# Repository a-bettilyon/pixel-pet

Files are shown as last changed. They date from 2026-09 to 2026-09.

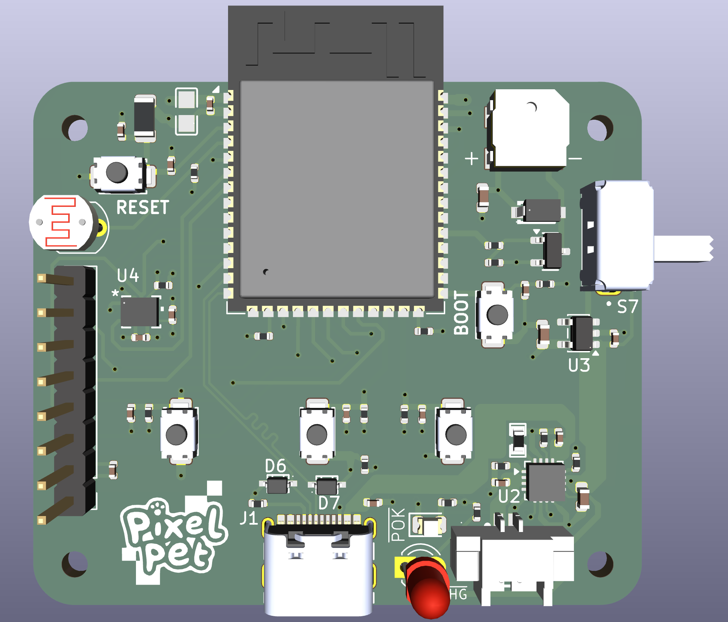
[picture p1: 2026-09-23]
hardware/images/VirtualPetBoardRenderV1.png

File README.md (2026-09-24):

PixelPetLogoFullColor

<br>

⚠️ **Project Status:** Active Development / Work in Progress

<br clear="left">
<br>

PixelPetV3Disassembled4

<br>

Pixel Pet is a handheld ESP32-S3-based device that brings back the virtual pet experience, built entirely from scratch, including custom PCB, 3D printed enclosure, and original C++ firmware.

The board features a 4-layer custom PCB design (ESP32-S3-WROOM-1, ST7789 TFT display, BMI323 IMU, LiPo charging with power path management, and tactile button input), fabricated and assembled through JLCPCB. The enclosure is designed in Fusion 360 and 3D printed to house the board, display, and battery in a compact handheld form factor.

This project was built as a hands-on portfolio piece to demonstrate end-to-end embedded systems and PCB design skills across schematic capture, layout, firmware development, and mechanical design.

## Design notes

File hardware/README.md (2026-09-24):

# Hardware

⚠️ **Status:** Active development. PCB currently in bring-up and testing.

KiCad project for the Pixel Pet custom PCB, an ESP32-S3-based board with display, IMU, charging circuit, and user I/O.

## Opening the project

Requires [KiCad](https://www.kicad.org/) (developed in v8). Multiple custom part libraries are used, see  `/libraries`.
## Key design notes

- ESP32-S3-WROOM-1 module, 4-layer board
- BQ24079 LiPo charger with power path management
- BMI323 IMU (SPI), ST7789 TFT display
- Targeting JLCPCB fabrication + SMT assembly, with select hand-soldered THT parts

## Gerbers / BOM freshness

Files in `/gerbers` and `bom.csv` are exported directly from the current `.kicad_pcb`/`.kicad_sch`. If you're building from this repo, pull these rather than any older exports that may exist elsewhere in project history.

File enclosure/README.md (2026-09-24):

# Enclosure

⚠️ **Status:** Active development.

<br>

PixelPetAssembledView3

<br>

3D-printable enclosure for the Pixel Pet handheld, designed around the PCB from `/hardware`.

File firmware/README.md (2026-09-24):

# Firmware

⚠️ **Status:** Active development.

## Building

_(Add your toolchain details here, e.g.)_
- Built with the Arduino IDE / PlatformIO targeting ESP32-S3
- Required libraries: _7Semi BMI323, Adafruit GFX Library, Adafruit ST7735 and ST7789 Library_

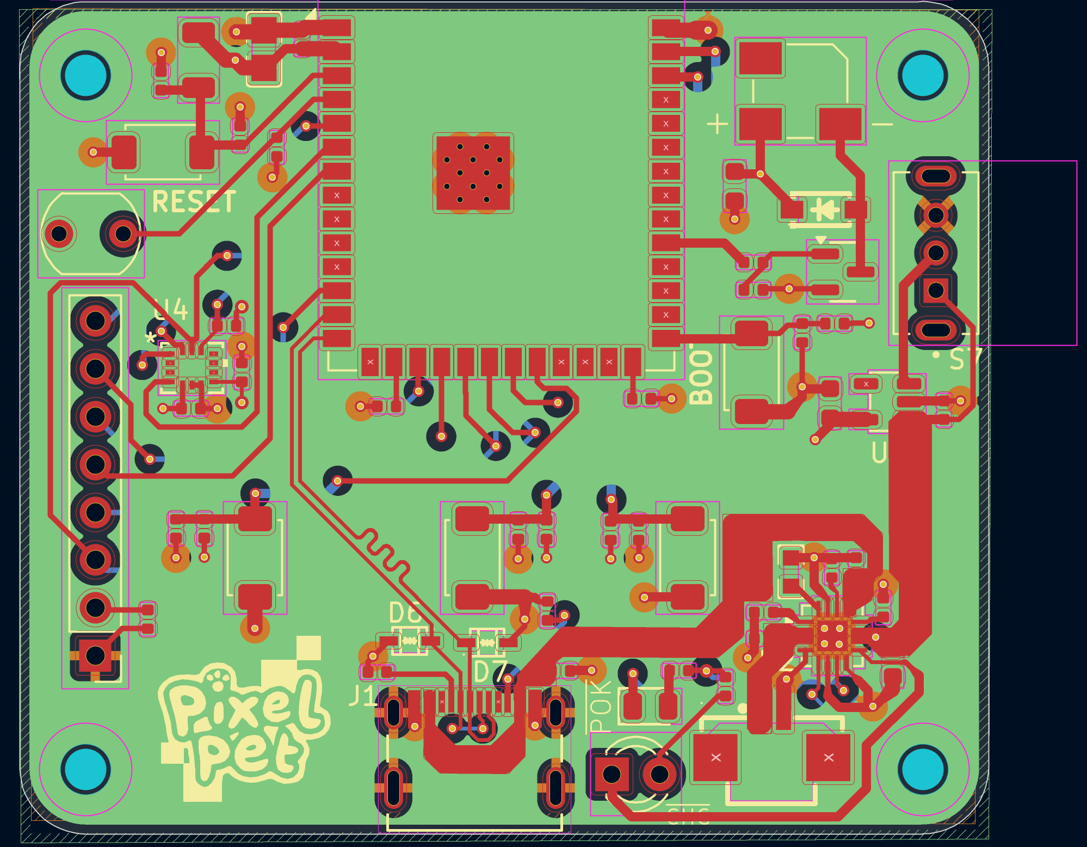
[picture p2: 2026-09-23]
hardware/images/VirtualPetBoardPCBAll.png

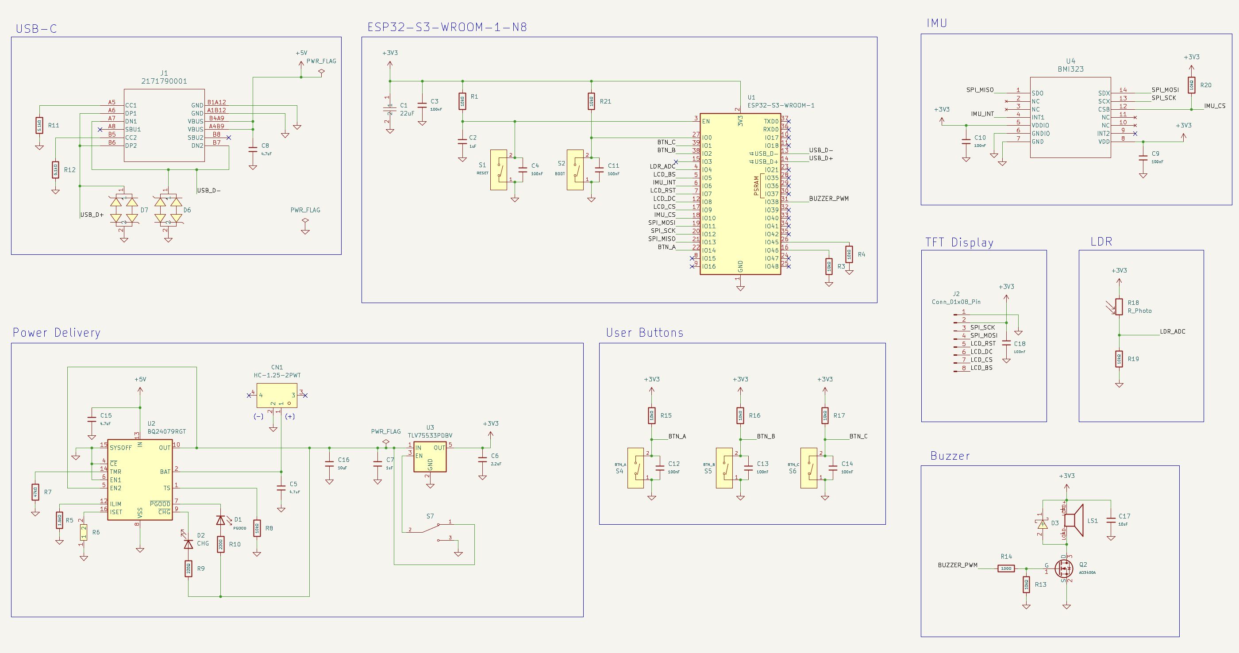
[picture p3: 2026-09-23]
hardware/images/VirtualPetBoardSchematicV1.png

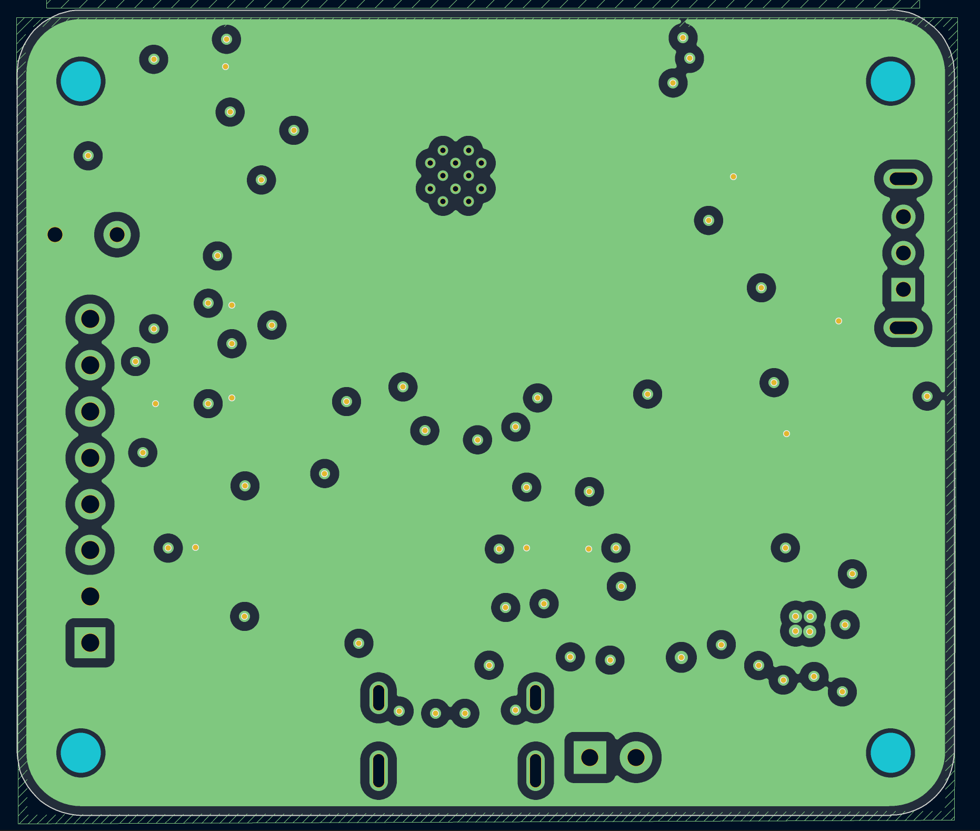
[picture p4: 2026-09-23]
hardware/images/VirtualPetBoardPCBLn1Cu.png

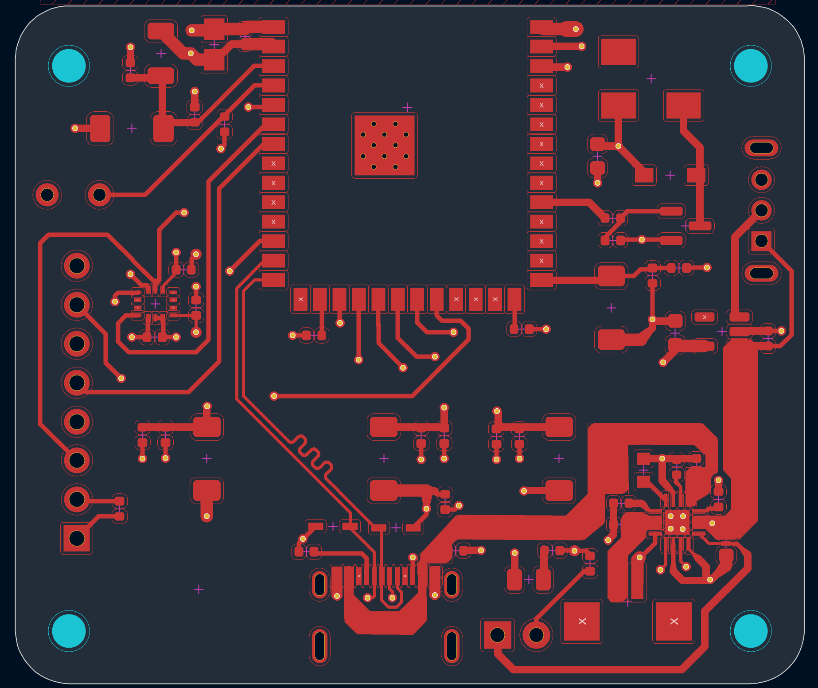
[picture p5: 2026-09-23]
hardware/images/VirtualPetBoardPCBFCu.png

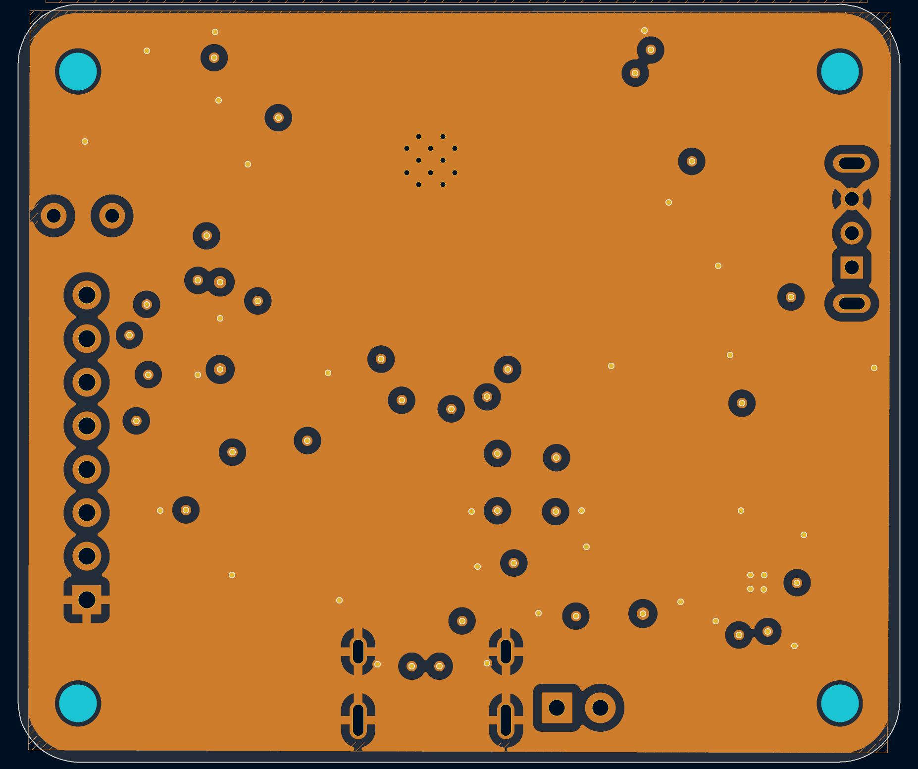
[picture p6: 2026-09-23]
hardware/images/VirtualPetBoardPCBLn2Cu.png

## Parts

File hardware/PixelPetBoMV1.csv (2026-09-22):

 | Status | Reference | Value | Footprint | LCSC | Part | Manufacturer | Description | Datasheet/Listing
1 | Basic | C1 | 22uF | C0805 | C45783 | CL21A226MAQNNNE | SAMSUNG(三星) |  | https://lcsc.com/product-detail/Multilayer-Ceramic-Capacitors-MLCC-SMD-SMT_SAMSUNG_CL21A226MAQNNNE_22uF-226-20-25V_C45783.html
2 | Basic | C2 | 1uF | C_0402 | C52923 | CL05A105KA5NQNC | Samsung Electro-Mechanics | 25V 1uF X5R ±10% 0402 Multilayer Ceramic Capacitors MLCC - SMD/SMT ROHS | https://www.lcsc.com/datasheet/lcsc_datasheet_2304140030_Samsung-Electro-Mechanics-CL05A105KA5NQNC_C52923.pdf
3 | Basic | C3 | 100nF | C_0402 | C1525 | CL05B104KO5NNNC | Samsung Electro-Mechanics | 16V 100nF X7R ±10% 0402 Multilayer Ceramic Capacitors MLCC - SMD/SMT ROHS | https://www.lcsc.com/datasheet/lcsc_datasheet_2304140030_Samsung-Electro-Mechanics-CL05B104KO5NNNC_C1525.pdf
4 | Basic | C4 | 100nF | C_0402 | C1525 | CL05B104KO5NNNC | Samsung Electro-Mechanics | 16V 100nF X7R ±10% 0402 Multilayer Ceramic Capacitors MLCC - SMD/SMT ROHS | https://www.lcsc.com/datasheet/lcsc_datasheet_2304140030_Samsung-Electro-Mechanics-CL05B104KO5NNNC_C1525.pdf
5 | Basic | C5 | 4.7uF | C_0402 | C23733 | CL05A475MP5NRNC | Samsung Electro-Mechanics | 10V 4.7uF X5R ±20% 0402 Multilayer Ceramic Capacitors MLCC - SMD/SMT ROHS | https://www.lcsc.com/datasheet/lcsc_datasheet_2304140030_Samsung-Electro-Mechanics-CL05A475MP5NRNC_C23733.pdf
6 | Basic | C6 | 2.2uF | C_0603 | C23630 | CL10A225KO8NNNC | Samsung Electro-Mechanics | 16V 2.2uF X5R ±10% 0603 Multilayer Ceramic Capacitors MLCC - SMD/SMT ROHS | https://www.lcsc.com/datasheet/lcsc_datasheet_2304140030_Samsung-Electro-Mechanics-CL10A225KO8NNNC_C23630.pdf
7 | Basic | C7 | 1uF | C_0402 | C52923 | CL05A105KA5NQNC | Samsung Electro-Mechanics | 25V 1uF X5R ±10% 0402 Multilayer Ceramic Capacitors MLCC - SMD/SMT ROHS | https://www.lcsc.com/datasheet/lcsc_datasheet_2304140030_Samsung-Electro-Mechanics-CL05A105KA5NQNC_C52923.pdf
8 | Basic | C8 | 4.7uF | C_0402 | C23733 | CL05A475MP5NRNC | Samsung Electro-Mechanics | 10V 4.7uF X5R ±20% 0402 Multilayer Ceramic Capacitors MLCC - SMD/SMT ROHS | https://www.lcsc.com/datasheet/lcsc_datasheet_2304140030_Samsung-Electro-Mechanics-CL05A475MP5NRNC_C23733.pdf
9 | Basic | C9 | 100nF | C_0402 | C1525 | CL05B104KO5NNNC | Samsung Electro-Mechanics | 16V 100nF X7R ±10% 0402 Multilayer Ceramic Capacitors MLCC - SMD/SMT ROHS | https://www.lcsc.com/datasheet/lcsc_datasheet_2304140030_Samsung-Electro-Mechanics-CL05B104KO5NNNC_C1525.pdf
10 | Basic | C10 | 100nF | C_0402 | C1525 | CL05B104KO5NNNC | Samsung Electro-Mechanics | 16V 100nF X7R ±10% 0402 Multilayer Ceramic Capacitors MLCC - SMD/SMT ROHS | https://www.lcsc.com/datasheet/lcsc_datasheet_2304140030_Samsung-Electro-Mechanics-CL05B104KO5NNNC_C1525.pdf
11 | Basic | C11 | 100nF | C_0402 | C1525 | CL05B104KO5NNNC | Samsung Electro-Mechanics | 16V 100nF X7R ±10% 0402 Multilayer Ceramic Capacitors MLCC - SMD/SMT ROHS | https://www.lcsc.com/datasheet/lcsc_datasheet_2304140030_Samsung-Electro-Mechanics-CL05B104KO5NNNC_C1525.pdf
12 | Basic | C12 | 100nF | C_0402 | C1525 | CL05B104KO5NNNC | Samsung Electro-Mechanics | 16V 100nF X7R ±10% 0402 Multilayer Ceramic Capacitors MLCC - SMD/SMT ROHS | https://www.lcsc.com/datasheet/lcsc_datasheet_2304140030_Samsung-Electro-Mechanics-CL05B104KO5NNNC_C1525.pdf
13 | Basic | C13 | 100nF | C_0402 | C1525 | CL05B104KO5NNNC | Samsung Electro-Mechanics | 16V 100nF X7R ±10% 0402 Multilayer Ceramic Capacitors MLCC - SMD/SMT ROHS | https://www.lcsc.com/datasheet/lcsc_datasheet_2304140030_Samsung-Electro-Mechanics-CL05B104KO5NNNC_C1525.pdf
14 | Basic | C14 | 100nF | C_0402 | C1525 | CL05B104KO5NNNC | Samsung Electro-Mechanics | 16V 100nF X7R ±10% 0402 Multilayer Ceramic Capacitors MLCC - SMD/SMT ROHS | https://www.lcsc.com/datasheet/lcsc_datasheet_2304140030_Samsung-Electro-Mechanics-CL05B104KO5NNNC_C1525.pdf
15 | Basic | C15 | 4.7uF | C_0402 | C23733 | CL05A475MP5NRNC | Samsung Electro-Mechanics | 10V 4.7uF X5R ±20% 0402 Multilayer Ceramic Capacitors MLCC - SMD/SMT ROHS | https://www.lcsc.com/datasheet/lcsc_datasheet_2304140030_Samsung-Electro-Mechanics-CL05A475MP5NRNC_C23733.pdf
16 | Basic | C16 | 10uF | C_0603 | C19702 | CL10A106KP8NNNC | Samsung Electro-Mechanics | 10V 10uF X5R ±10% 0603 Multilayer Ceramic Capacitors MLCC - SMD/SMT ROHS | https://www.lcsc.com/datasheet/lcsc_datasheet_2304140030_Samsung-Electro-Mechanics-CL10A106KP8NNNC_C19702.pdf
17 | Basic | C17 | 10uF | C_0603 | C19702 | CL10A106KP8NNNC | Samsung Electro-Mechanics | 10V 10uF X5R ±10% 0603 Multilayer Ceramic Capacitors MLCC - SMD/SMT ROHS | https://www.lcsc.com/datasheet/lcsc_datasheet_2304140030_Samsung-Electro-Mechanics-CL10A106KP8NNNC_C19702.pdf
18 | Basic | C18 | 100nF | C_0402 | C1525 | CL05B104KO5NNNC | Samsung Electro-Mechanics | 16V 100nF X7R ±10% 0402 Multilayer Ceramic Capacitors MLCC - SMD/SMT ROHS | https://www.lcsc.com/datasheet/lcsc_datasheet_2304140030_Samsung-Electro-Mechanics-CL05B104KO5NNNC_C1525.pdf
19 | Basic | R1 | 10kΩ | R_1206 | C17902 | 1206W4F1002T5E | UNI-ROYAL(Uniroyal Elec) | 250mW Thick Film Resistors 200V ±100ppm/°C ±1% 10kΩ 1206 Chip Resistor - Surface Mount ROHS | https://www.lcsc.com/datasheet/lcsc_datasheet_2206010145_UNI-ROYAL-Uniroyal-Elec-1206W4F1002T5E_C17902.pdf
20 | Basic | R3 | 10kΩ | R_0402 | C25744 | 0402WGF1002TCE | UNI-ROYAL(Uniroyal Elec) | 62.5mW Thick Film Resistors 50V ±100ppm/°C ±1% 10kΩ 0402 Chip Resistor - Surface Mount ROHS | https://www.lcsc.com/datasheet/lcsc_datasheet_2411221126_UNI-ROYAL-Uniroyal-Elec-0402WGF1002TCE_C25744.pdf
21 | Basic | R4 | 10kΩ | R_0402 | C25744 | 0402WGF1002TCE | UNI-ROYAL(Uniroyal Elec) | 62.5mW Thick Film Resistors 50V ±100ppm/°C ±1% 10kΩ 0402 Chip Resistor - Surface Mount ROHS | https://www.lcsc.com/datasheet/lcsc_datasheet_2411221126_UNI-ROYAL-Uniroyal-Elec-0402WGF1002TCE_C25744.pdf
22 | Basic | R5 | 1.5kΩ | R_0402 | C25867 | 0402WGF1501TCE | UNI-ROYAL(Uniroyal Elec) | 62.5mW Thick Film Resistors 50V ±100ppm/°C ±1% 1.5kΩ 0402 Chip Resistor - Surface Mount ROHS | https://www.lcsc.com/datasheet/lcsc_datasheet_2206010045_UNI-ROYAL-Uniroyal-Elec-0402WGF1501TCE_C25867.pdf
23 | Basic | R6 | 3.9k | R0603 | C23018 | 0603WAF3901T5E | UNI-ROYAL(厚声) | 3.9KΩ (3901) ±1% | https://lcsc.com/product-detail/Chip-Resistor-Surface-Mount-UniOhm_3-9KR-3901-1_C23018.html
24 | Basic | R7 | 47kΩ | R_0402 | C25792 | 0402WGF4702TCE | UNI-ROYAL(Uniroyal Elec) | 62.5mW Thick Film Resistors 50V ±100ppm/°C ±1% 47kΩ 0402 Chip Resistor - Surface Mount ROHS | https://www.lcsc.com/datasheet/lcsc_datasheet_2206010100_UNI-ROYAL-Uniroyal-Elec-0402WGF4702TCE_C25792.pdf
25 | Basic | R8 | 10kΩ | R_0402 | C25744 | 0402WGF1002TCE | UNI-ROYAL(Uniroyal Elec) | 62.5mW Thick Film Resistors 50V ±100ppm/°C ±1% 10kΩ 0402 Chip Resistor - Surface Mount ROHS | https://www.lcsc.com/datasheet/lcsc_datasheet_2411221126_UNI-ROYAL-Uniroyal-Elec-0402WGF1002TCE_C25744.pdf
26 | Basic | R9 | 220Ω | R_0402 | C25091 | 0402WGF2200TCE | UNI-ROYAL(Uniroyal Elec) | 62.5mW Thick Film Resistors 50V ±100ppm/°C ±1% 220Ω 0402 Chip Resistor - Surface Mount ROHS | https://www.lcsc.com/datasheet/lcsc_datasheet_2205311900_UNI-ROYAL-Uniroyal-Elec-0402WGF2200TCE_C25091.pdf
27 | Basic | R10 | 220Ω | R_0402 | C25091 | 0402WGF2200TCE | UNI-ROYAL(Uniroyal Elec) | 62.5mW Thick Film Resistors 50V ±100ppm/°C ±1% 220Ω 0402 Chip Resistor - Surface Mount ROHS | https://www.lcsc.com/datasheet/lcsc_datasheet_2205311900_UNI-ROYAL-Uniroyal-Elec-0402WGF2200TCE_C25091.pdf
28 | Basic | R11 | 5.1kΩ | R_0402 | C25905 | 0402WGF5101TCE | UNI-ROYAL(Uniroyal Elec) | 62.5mW Thick Film Resistors 50V ±100ppm/°C ±1% 5.1kΩ 0402 Chip Resistor - Surface Mount ROHS | https://www.lcsc.com/datasheet/lcsc_datasheet_2206010045_UNI-ROYAL-Uniroyal-Elec-0402WGF5101TCE_C25905.pdf
29 | Basic | R12 | 5.1kΩ | R_0402 | C25905 | 0402WGF5101TCE | UNI-ROYAL(Uniroyal Elec) | 62.5mW Thick Film Resistors 50V ±100ppm/°C ±1% 5.1kΩ 0402 Chip Resistor - Surface Mount ROHS | https://www.lcsc.com/datasheet/lcsc_datasheet_2206010045_UNI-ROYAL-Uniroyal-Elec-0402WGF5101TCE_C25905.pdf
30 | Basic | R13 | 10kΩ | R_0402 | C25744 | 0402WGF1002TCE | UNI-ROYAL(Uniroyal Elec) | 62.5mW Thick Film Resistors 50V ±100ppm/°C ±1% 10kΩ 0402 Chip Resistor - Surface Mount ROHS | https://www.lcsc.com/datasheet/lcsc_datasheet_2411221126_UNI-ROYAL-Uniroyal-Elec-0402WGF1002TCE_C25744.pdf
31 | Basic | R14 | 100Ω | R_0402 | C25076 | 0402WGF1000TCE | UNI-ROYAL(Uniroyal Elec) | 62.5mW Thick Film Resistors 50V ±1% ±200ppm/°C 100Ω 0402 Chip Resistor - Surface Mount ROHS | https://www.lcsc.com/datasheet/lcsc_datasheet_2205311900_UNI-ROYAL-Uniroyal-Elec-0402WGF1000TCE_C25076.pdf
32 | Basic | R15 | 10kΩ | R_0402 | C25744 | 0402WGF1002TCE | UNI-ROYAL(Uniroyal Elec) | 62.5mW Thick Film Resistors 50V ±100ppm/°C ±1% 10kΩ 0402 Chip Resistor - Surface Mount ROHS | https://www.lcsc.com/datasheet/lcsc_datasheet_2411221126_UNI-ROYAL-Uniroyal-Elec-0402WGF1002TCE_C25744.pdf
33 | Basic | R16 | 10kΩ | R_0402 | C25744 | 0402WGF1002TCE | UNI-ROYAL(Uniroyal Elec) | 62.5mW Thick Film Resistors 50V ±100ppm/°C ±1% 10kΩ 0402 Chip Resistor - Surface Mount ROHS | https://www.lcsc.com/datasheet/lcsc_datasheet_2411221126_UNI-ROYAL-Uniroyal-Elec-0402WGF1002TCE_C25744.pdf
34 | Basic | R17 | 10kΩ | R_0402 | C25744 | 0402WGF1002TCE | UNI-ROYAL(Uniroyal Elec) | 62.5mW Thick Film Resistors 50V ±100ppm/°C ±1% 10kΩ 0402 Chip Resistor - Surface Mount ROHS | https://www.lcsc.com/datasheet/lcsc_datasheet_2411221126_UNI-ROYAL-Uniroyal-Elec-0402WGF1002TCE_C25744.pdf
35 | Basic | R18 | R_Photo | R_LDR_5.1x4.3mm_P3.4mm_Vertical |  |  |  | Photoresistor
36 | Basic | R19 | 10kΩ | R_0402 | C25744 | 0402WGF1002TCE | UNI-ROYAL(Uniroyal Elec) | 62.5mW Thick Film Resistors 50V ±100ppm/°C ±1% 10kΩ 0402 Chip Resistor - Surface Mount ROHS | https://www.lcsc.com/datasheet/lcsc_datasheet_2411221126_UNI-ROYAL-Uniroyal-Elec-0402WGF1002TCE_C25744.pdf
37 | Basic | R20 | 10kΩ | R_0402 | C25744 | 0402WGF1002TCE | UNI-ROYAL(Uniroyal Elec) | 62.5mW Thick Film Resistors 50V ±100ppm/°C ±1% 10kΩ 0402 Chip Resistor - Surface Mount ROHS | https://www.lcsc.com/datasheet/lcsc_datasheet_2411221126_UNI-ROYAL-Uniroyal-Elec-0402WGF1002TCE_C25744.pdf
38 | Basic | R21 | 10kΩ | R_0402 | C25744 | 0402WGF1002TCE | UNI-ROYAL(Uniroyal Elec) | 62.5mW Thick Film Resistors 50V ±100ppm/°C ±1% 10kΩ 0402 Chip Resistor - Surface Mount ROHS | https://www.lcsc.com/datasheet/lcsc_datasheet_2411221126_UNI-ROYAL-Uniroyal-Elec-0402WGF1002TCE_C25744.pdf
39 |  | D1 | PGOOD | D_0805 | C2297 | KT-0805G | Hubei KENTO Elec | Emerald 0805 LED Indication - Discrete ROHS | https://www.lcsc.com/datasheet/lcsc_datasheet_1806151820_Hubei-KENTO-Elec-KT-0805G_C2297.pdf
40 |  | D2 | CHG | LED_D3.0mm |  |  |  | Light emitting diode
41 |  | D3 | B5819W_C8598 | SOD-123_L2.7-W1.6-LS3.7-RD-1 | C8598 | B5819W SL | CJ(江苏长电/长晶) | B5819W SL | https://lcsc.com/product-detail/Schottky-Barrier-Diodes-SBD_B5819W-SL_C8598.html
42 |  | D6 | PTVSUC3D5VB | SOD-323_L1.8-W1.3-LS2.5-BI | C918847 | PTVSUC3D5VB | Prisemi(芯导) |  | https://lcsc.com/product-detail/TVS_Shanghai-Prisemi-Elec-PTVSUC3D5VB_C918847.html
43 |  | D7 | PTVSUC3D5VB | SOD-323_L1.8-W1.3-LS2.5-BI | C918847 | PTVSUC3D5VB | Prisemi(芯导) |  | https://lcsc.com/product-detail/TVS_Shanghai-Prisemi-Elec-PTVSUC3D5VB_C918847.html
44 |  | U1 | ESP32-S3-WROOM-1 | ESP32-S3-WROOM-1-Custom |  |  |  | RF Module, ESP32-S3 SoC, Wi-Fi 802.11b/g/n, Bluetooth, BLE, 32-bit, 3.3V, onboard antenna, SMD | https://www.espressif.com/sites/default/files/documentation/esp32-s3-wroom-1_wroom-1u_datasheet_en.pdf
45 |  | U2 | BQ24079RGT | VQFN-16-1EP_3x3mm_P0.5mm_EP1.6x1.6mm |  |  |  | USB-Friendly Li-Ion Battery Charger and Power-Path Management, VQFN-16 | http://www.ti.com/lit/ds/symlink/bq24079.pdf
46 |  | U3 | TLV75533PDBV | SOT-23-5 |  |  |  | 500mA Low Dropout Voltage Regulator, Fixed Output 3.3V, SOT-23-5 | http://www.ti.com/lit/ds/symlink/tlv755p.pdf
47 | Extended - JLC Assembly | U4 | BMI323 | BMI323_BOS
48 | Extended - JLC Assembly | CN1 | HC-1.25-2PWT | CONN-SMD_2P-P1.25-HC-1.25-2PWT | C2845379 | HC-1.25-2PWT | HCTL(华灿天禄) |  | https://www.lcsc.com/datasheet/C2845379.pdf
49 | Extended - JLC Assembly | LS1 | SMT-0540-T-9-R | XDCR_SMT-0540-T-9-R | C3812059 | SMT-0540-T-9-R
50 | Basic | Q2 | AO3400A | Q_SOT-23 | C20917 | AO3400A | Alpha & Omega Semicon | 30V 5.7A 26.5mΩ@10V,5.7A 1.4W 1.5V@250uA 1 N-Channel SOT-23-3L MOSFETs ROHS | https://www.lcsc.com/datasheet/lcsc_datasheet_1811081213_Alpha---Omega-Semicon-AO3400A_C20917.pdf
51 | Basic | S1 | RESET | SW_TS-1088-AR02016 | C720477 | TS-1088-AR02016 | XUNPU | Without 50mA 4mm 100MΩ 100000 Times 12V 160gf 3mm 2mm Round Button Standing paste SPST SMD Tactile Switches ROHS | https://www.lcsc.com/datasheet/lcsc_datasheet_2304140030_XUNPU-TS-1088-AR02016_C720477.pdf
52 | Basic | S2 | BOOT | SW_TS-1088-AR02016 | C720477 | TS-1088-AR02016 | XUNPU | Without 50mA 4mm 100MΩ 100000 Times 12V 160gf 3mm 2mm Round Button Standing paste SPST SMD Tactile Switches ROHS | https://www.lcsc.com/datasheet/lcsc_datasheet_2304140030_XUNPU-TS-1088-AR02016_C720477.pdf
53 | Digikey | S4 | BTN_A | SW_TS02-66-160-BK-160-LCR-D |  | TS02-66-160-BK-160-LCR-D
54 | Digikey | S5 | BTN_B | SW_TS02-66-160-BK-160-LCR-D |  | TS02-66-160-BK-160-LCR-D
55 | Digikey | S6 | BTN_C | SW_TS02-66-160-BK-160-LCR-D |  | TS02-66-160-BK-160-LCR-D
56 | Extended - Self Solder | S7 | SLW-864574-5A-RA-N-D | SW_SLW-864574-5A-RA-N-D |  | TS02-66-160-BK-160-LCR-D
57 | Extended - JLC Assembly | J1 | 2171790001 | 2171790001_MOL | C3197684 |  |  |  | https://www.molex.com/en-us/products/part-detail-pdf/2171790001?display=pdf
58 | Amazon | J2 | Conn_01x08_Pin | PinHeader_1x08_P2.54mm_Vertical |  |  |  | Generic connector, single row, 01x08, script generated
59 | M2 Self-Tapping Flat Head Screws |  |  |  |  |  |  |  | https://www.amazon.com/gp/product/B0CY986CCR/ref=ox_sc_act_title_1?smid=A149PLON3AQQ4N&psc=1
60 | 1.54" SPI TFT Display Module |  |  |  |  |  |  |  | https://www.amazon.com/gp/product/B0DN9NMBFW/ref=ox_sc_act_title_4?smid=A1ASY00QOMN6RD&psc=1
61 | LiPo Battery 3.7V 1.15Ah |  |  |  |  |  |  |  | https://www.digikey.com/en/products/detail/jauch-quartz/LP384260JU-PCM-MOLEX-51021-0200-35MM/22528194
62
63
64

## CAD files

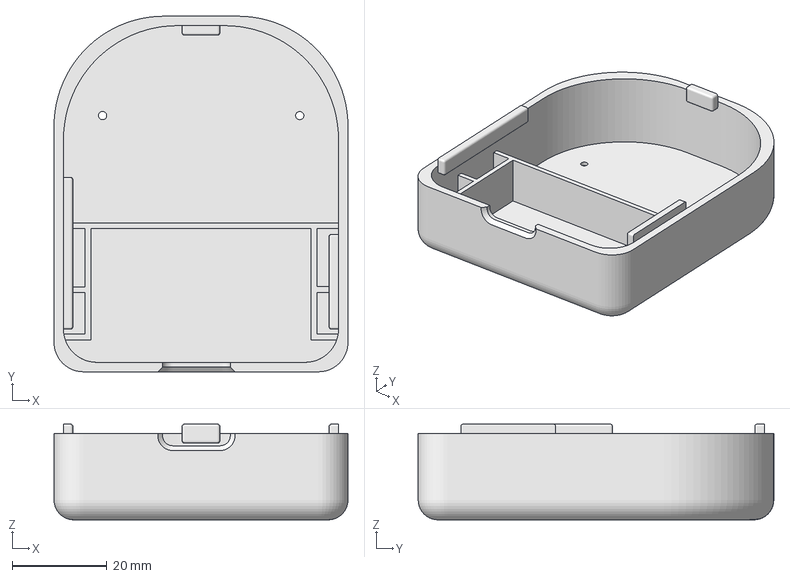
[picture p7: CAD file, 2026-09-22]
enclosure/EnclosureBottomV2.3mf
62.0 x 75.0 x 20.2 mm

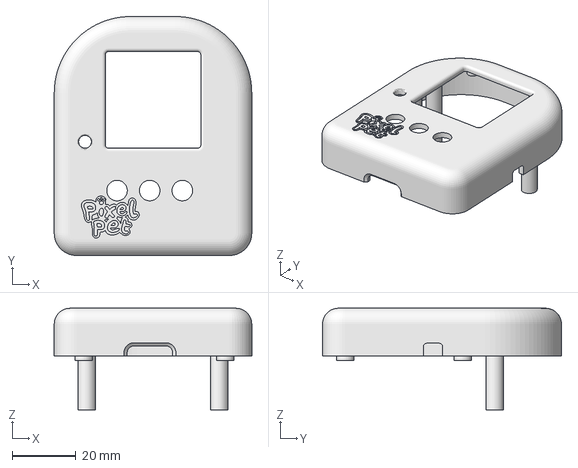
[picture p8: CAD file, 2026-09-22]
enclosure/EnclosureTopV2.3mf
62.0 x 75.0 x 31.9 mm

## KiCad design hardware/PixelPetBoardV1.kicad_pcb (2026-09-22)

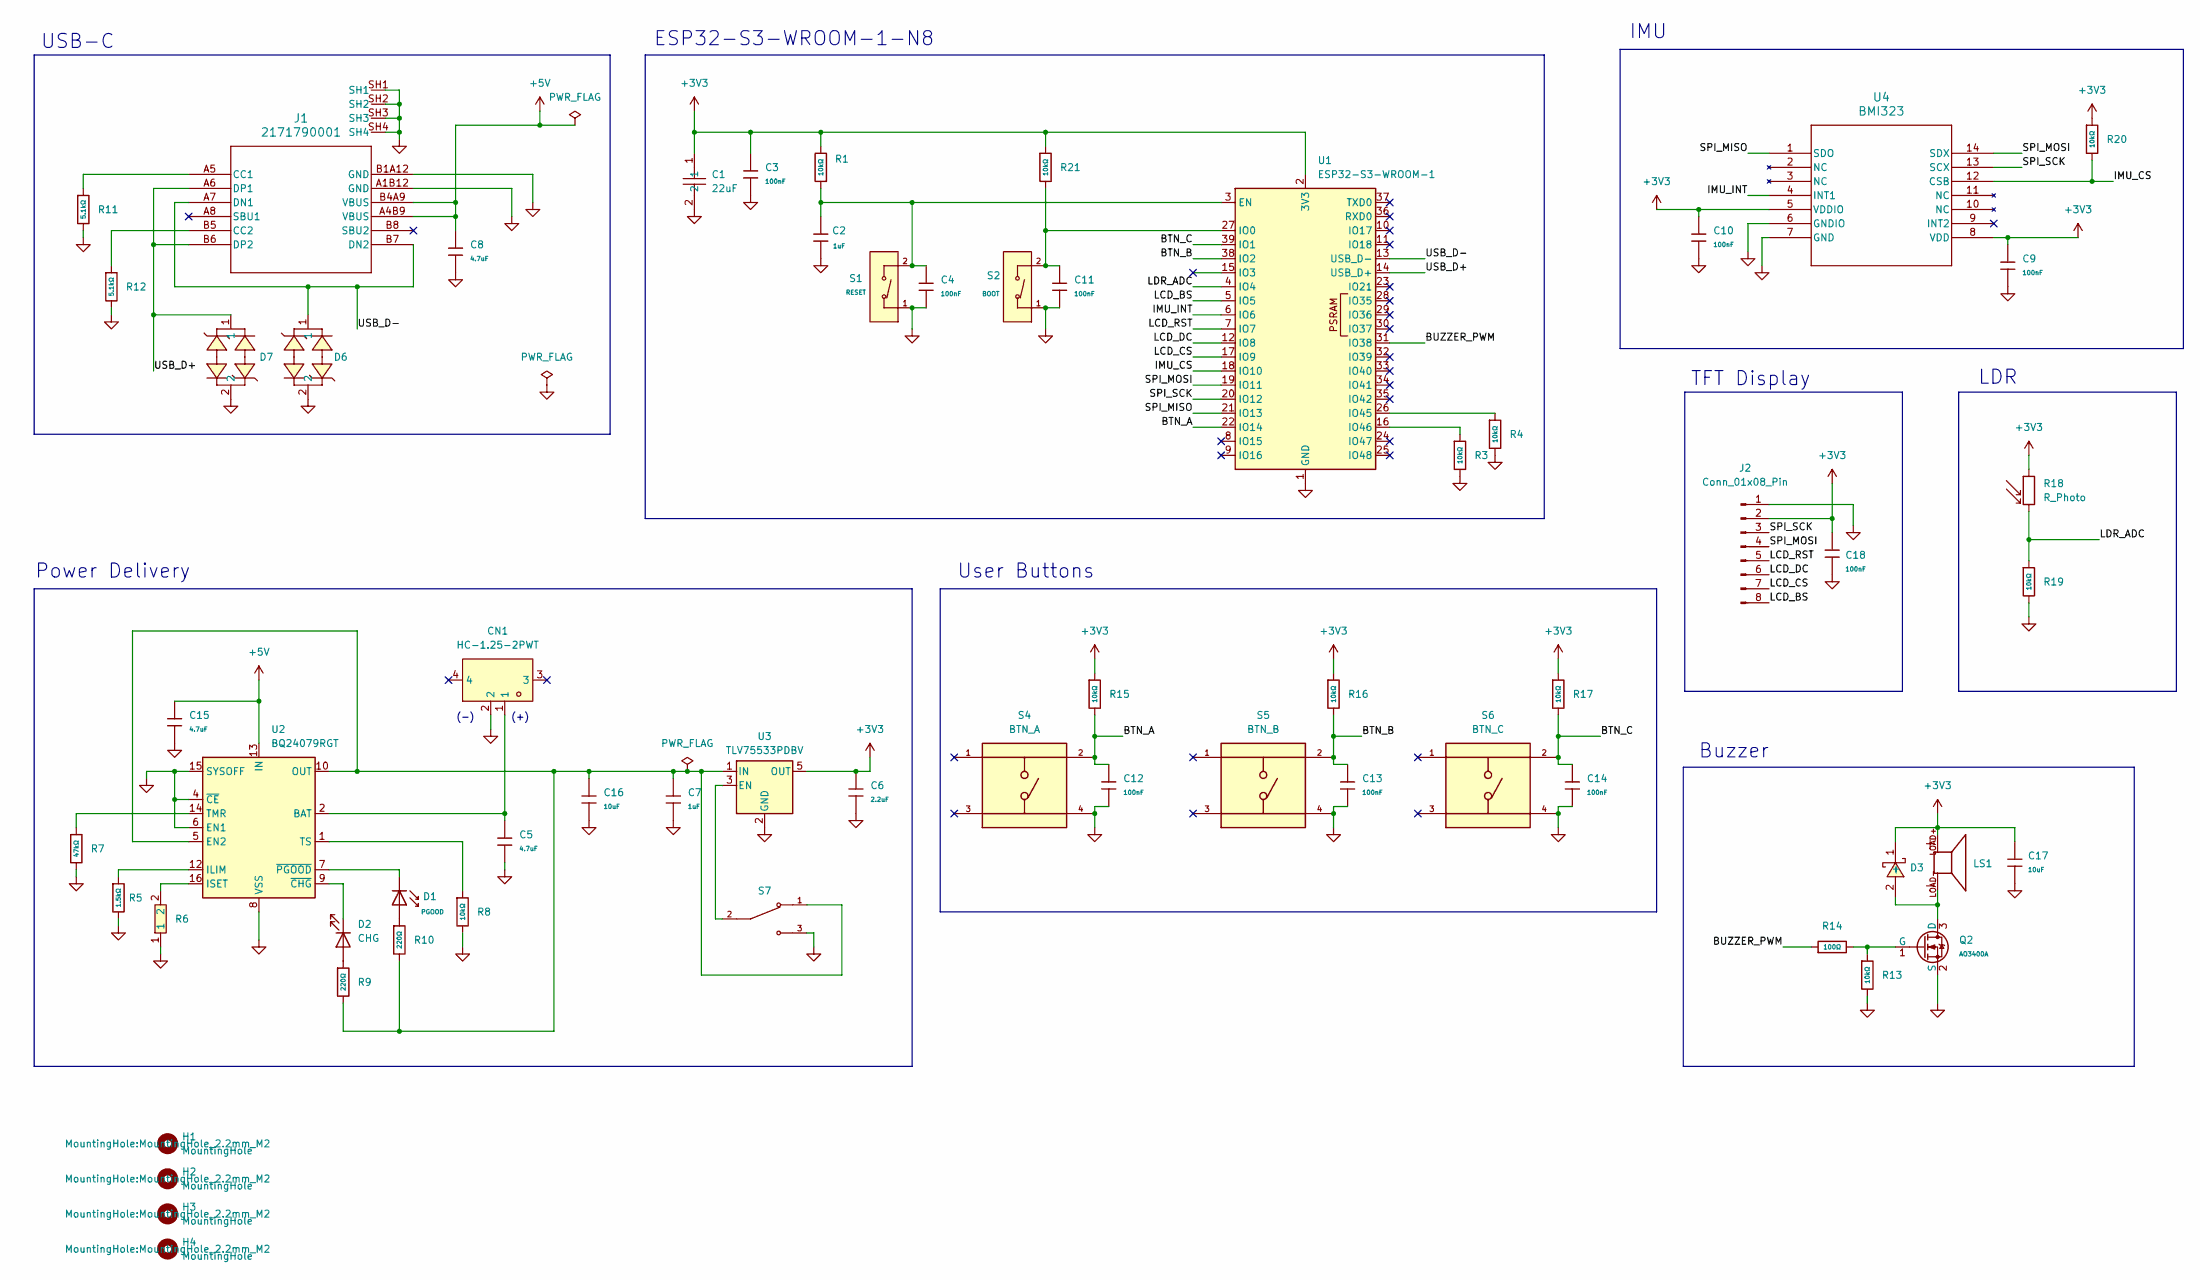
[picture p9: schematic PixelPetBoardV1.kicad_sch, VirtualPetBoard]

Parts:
C1: 22uF; C0805; MPN CL21A226MAQNNNE; LCSC Part C45783
C2, C7: 1uF; C_0402; Voltage Rated 25V; Tolerance ±10%; Part CL05A105KA5NQNC; LCSC C52923
C3, C4, C9, C10, C11, C12, C13, C14, C18: 100nF; C_0402; Voltage Rated 16V; Tolerance ±10%; Part CL05B104KO5NNNC; LCSC C1525
C5, C8, C15: 4.7uF; C_0402; Voltage Rated 10V; Tolerance ±20%; Part CL05A475MP5NRNC; LCSC C23733
C6: 2.2uF; C_0603; Voltage Rated 16V; Tolerance ±10%; Part CL10A225KO8NNNC; LCSC C23630
C16, C17: 10uF; C_0603; Voltage Rated 10V; Tolerance ±10%; Part CL10A106KP8NNNC; LCSC C19702
CN1: HC-1.25-2PWT; CONN-SMD_2P-P1.25-HC-1.25-2PWT; MPN HC-1.25-2PWT; LCSC Part C2845379
D1: PGOOD; D_0805; Part KT-0805G; LCSC C2297
D2: CHG; LED_D3.0mm
D3: B5819W_C8598; SOD-123_L2.7-W1.6-LS3.7-RD-1; MPN B5819W SL; LCSC Part C8598
D6, D7: PTVSUC3D5VB; SOD-323_L1.8-W1.3-LS2.5-BI; MPN PTVSUC3D5VB; LCSC Part C918847
H1, H2, H3, H4: MountingHole; MountingHole_2.2mm_M2
J1: 2171790001; 2171790001_MOL
J2: Conn_01x08_Pin; PinHeader_1x08_P2.54mm_Vertical
LS1: SMT-0540-T-9-R; XDCR_SMT-0540-T-9-R; PARTREV A
Q2: AO3400A; Q_SOT-23; Part AO3400A; LCSC C20917
R1: 10kΩ; R_1206; Overload Voltage (Max) 200V; Tolerance ±1%; Part 1206W4F1002T5E; LCSC C17902
R3, R4, R8, R13, R15, R16, R17, R19, R20, R21: 10kΩ; R_0402; Overload Voltage (Max) 50V; Tolerance ±1%; Part 0402WGF1002TCE; LCSC C25744
R5: 1.5kΩ; R_0402; Overload Voltage (Max) 50V; Tolerance ±1%; Part 0402WGF1501TCE; LCSC C25867
R6: 3.9k; R0603; MPN 0603WAF3901T5E; LCSC Part C23018
R7: 47kΩ; R_0402; Overload Voltage (Max) 50V; Tolerance ±1%; Part 0402WGF4702TCE; LCSC C25792
R9, R10: 220Ω; R_0402; Overload Voltage (Max) 50V; Tolerance ±1%; Part 0402WGF2200TCE; LCSC C25091
R11, R12: 5.1kΩ; R_0402; Overload Voltage (Max) 50V; Tolerance ±1%; Part 0402WGF5101TCE; LCSC C25905
R14: 100Ω; R_0402; Overload Voltage (Max) 50V; Tolerance ±1%; Part 0402WGF1000TCE; LCSC C25076
R18: R_Photo; R_LDR_5.1x4.3mm_P3.4mm_Vertical
S1: RESET; SW_TS-1088-AR02016; Voltage Rating (Dc) 12V; Part TS-1088-AR02016; LCSC C720477
S2: BOOT; SW_TS-1088-AR02016; Voltage Rating (Dc) 12V; Part TS-1088-AR02016; LCSC C720477
S4: BTN_A; SW_TS02-66-160-BK-160-LCR-D; PARTREV 1.0
S5: BTN_B; SW_TS02-66-160-BK-160-LCR-D; PARTREV 1.0
S6: BTN_C; SW_TS02-66-160-BK-160-LCR-D; PARTREV 1.0
S7: SLW-864574-5A-RA-N-D; SW_SLW-864574-5A-RA-N-D; PARTREV 1.01
U1: ESP32-S3-WROOM-1; ESP32-S3-WROOM-1-Custom
U2: BQ24079RGT; VQFN-16-1EP_3x3mm_P0.5mm_EP1.6x1.6mm
U3: TLV75533PDBV; SOT-23-5
U4: BMI323; BMI323_BOS

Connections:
+3V3: C1.1, C3.1, C6.1, C9.2, C10.1, C17.1, C18.1, D3.1 (-), J2.2, LS1.LOAD+, R1.2, R15.1, R16.1, R17.1, R18.1, R20.1, R21.1, U1.2 (3V3), U3.5 (OUT), U4.5 (VDDIO), U4.8 (VDD)
+5V: C8.1, C15.1, J1.A4B9 (VBUS), J1.B4A9 (VBUS), U2.13 (IN)
/BTN_A: C12.1, R15.2, S4.2, U1.22 (IO14)
/BTN_B: C13.1, R16.2, S5.2, U1.38 (IO2)
/BTN_C: C14.1, R17.2, S6.2, U1.39 (IO1)
/BUZZER_PWM: R14.1, U1.31 (IO38)
/IMU_CS: R20.2, U1.18 (IO10), U4.12 (CSB)
/IMU_INT: U1.6 (IO6), U4.4 (INT1)
/LCD_BS: J2.8, U1.5 (IO5)
/LCD_CS: J2.7, U1.17 (IO9)
/LCD_DC: J2.6, U1.12 (IO8)
/LCD_RST: J2.5, U1.7 (IO7)
/LDR_ADC: R18.2, R19.1, U1.4 (IO4)
/SPI_MISO: U1.21 (IO13), U4.1 (SDO)
/SPI_MOSI: J2.4, U1.19 (IO11), U4.14 (SDX)
/SPI_SCK: J2.3, U1.20 (IO12), U4.13 (SCX)
/USB_D+: D7.1, J1.A6 (DP1), J1.B6 (DP2), U1.14 (USB_D+)
/USB_D-: D6.1, J1.A7 (DN1), J1.B7 (DN2), U1.13 (USB_D-)
GND: C1.2, C2.1, C3.2, C4.2, C5.2, C6.2, C7.2, C8.2, C9.1, C10.2, C11.2, C12.2, C13.2, C14.2, C15.2, C16.2, C17.2, C18.2, CN1.2, D6.2, D7.2, J1.A1B12 (GND), J1.B1A12 (GND), J1.SH1, J1.SH2, J1.SH3, J1.SH4, J2.1, Q2.2 (S), R3.2, R4.2, R5.2, R6.1, R7.2, R8.2, R11.2, R12.2, R13.2, R19.2, S1.1 (A), S2.1 (A), S4.4, S5.4, S6.4, S7.3, U1.1 (GND), U1.40 (GND), U1.41 (GND), U2.4 (~CE), U2.6 (EN1), U2.8 (VSS), U2.15 (SYSOFF), U2.17 (VSS), U3.2 (GND), U4.6 (GNDIO), U4.7 (GND)
unnamed: C5.1, CN1.1, U2.2 (BAT), U2.3 (BAT)
unnamed: D1.2, R10.1
unnamed: D2.2 (A), R9.1
unnamed: D2.1 (K), U2.9 (~CHG)
unnamed: D3.2 (+), LS1.LOAD-, Q2.3 (D)
unnamed: J1.A5 (CC1), R11.1
unnamed: J1.B5 (CC2), R12.1
unnamed: Q2.1 (G), R13.1, R14.2
unnamed: C2.2, C4.1, R1.1, S1.2 (B), U1.3 (EN)
unnamed: C11.1, R21.2, S2.2 (B), U1.27 (IO0)
unnamed: R4.1, U1.26 (IO45)
unnamed: R3.1, U1.16 (IO46)
unnamed: C7.1, C16.1, R9.2, R10.2, S7.1, U2.5 (EN2), U2.10 (OUT), U2.11 (OUT), U3.1 (IN)
unnamed: R5.1, U2.12 (ILIM)
unnamed: R6.2, U2.16 (ISET)
unnamed: R7.1, U2.14 (TMR)
unnamed: R8.1, U2.1 (TS)
unnamed: D1.1, U2.7 (~PGOOD)
unnamed: S7.2, U3.3 (EN)

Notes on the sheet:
Buzzer
ESP32-S3-WROOM-1-N8
(+)
LDR
IMU
(-)
TFT Display
User Buttons
USB-C
Power Delivery

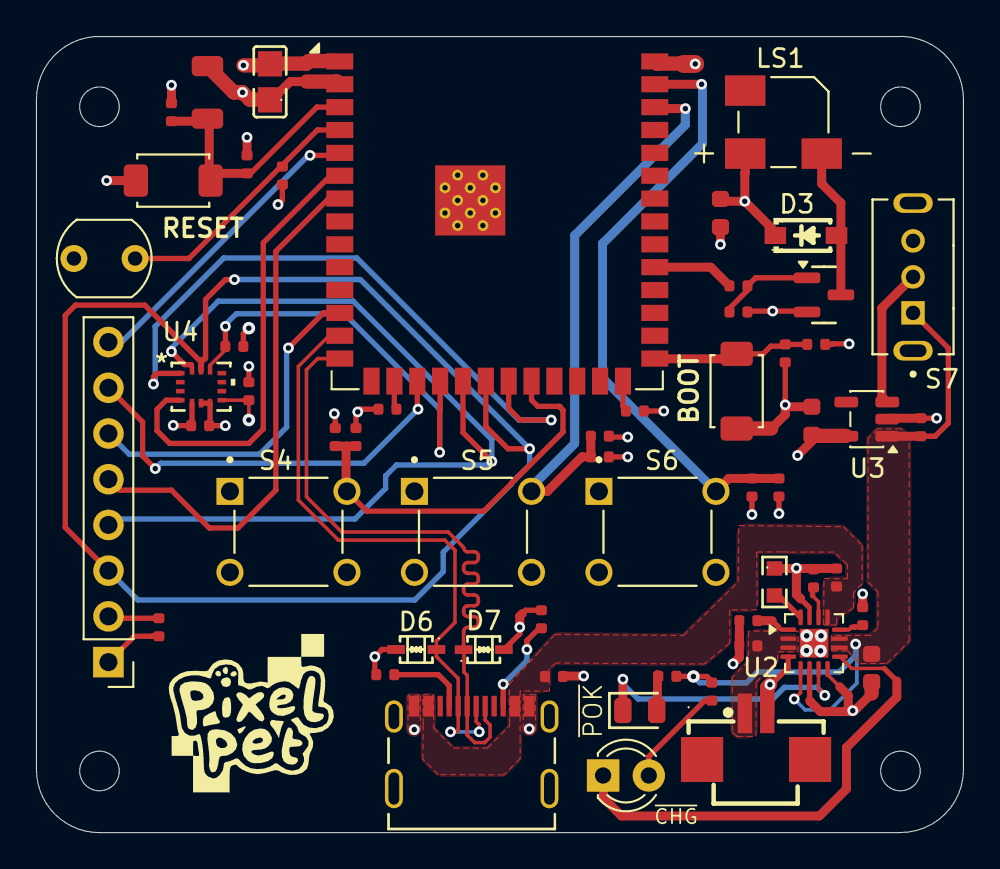
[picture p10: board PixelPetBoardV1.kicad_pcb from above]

Board: 4 copper layers, 51.5 x 44.2 mm, 62 parts (0 on the bottom side), 38 nets.

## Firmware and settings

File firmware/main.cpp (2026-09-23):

// #include <Arduino_DataBus.h>
// #include <Arduino_G.h>
// #include <Arduino_GFX.h>
// #include <Arduino_GFX_Library.h>
// #include <Arduino_OLED.h>
// #include <Arduino_TFT.h>
// #include <Arduino_TFT_18bit.h>
// #include <YCbCr2RGB.h>
// #include <gfxfont.h>

// #include <Adafruit_ST7735.h>
// #include <Adafruit_ST7789.h>
// #include <Adafruit_ST7796S.h>
// #include <Adafruit_ST77xx.h>

/* Pixel Pet ESP32 Code */

/* Peripherals List

1. 2171790001 USB-C Receptacle: Differential Pair
    D+ on pin 14
    D- on pin 13

2. BMI323 Gyrometer/Accelerometer: SPI
    MOSI on pin 19 (IO11)
    MISO on pin 21 (IO13)
    SCK on pin 20 (IO12)
    CS on pin 18 (IO10)
    
3. ST7789 TFT Display: SPI
    MOSI on pin 19 (IO11)
    no MISO
    SCK on pin 20 (IO12)
    CS on pin 17 (IO9)
    RST on pin 7 (IO7)
    DC on pin 12 (IO8)
    BS on pin 5 (IO5)

4. LDR: ADC
    ADC on pin 4 (IO4)

5. Buttons
    BTN A on pin 22 (IO14)
    BTN_B on pin 38 (IO2)
    BTN_C on pin 39 (IO1)
    BOOT on pin 27 (IO0) - active LOW
    RESET on pin 3 (EN) - active LOW

6. Buzzer
    BUZZER_PWM on pin 31 (IO38)

*/

#include <Arduino.h>
#include <Adafruit_ST7789.h>
#include <SPI.h>

#include "main.h"
#include "petState.h"
#include "buttons.h"
#include "display.h"


petState pixelPet;

void setup() {
    Serial.begin(9600);

    pinMode(BTN_A_PIN, INPUT_PULLUP);
    pinMode(BTN_B_PIN, INPUT_PULLUP);
    pinMode(BTN_C_PIN, INPUT_PULLUP);
    
    //IMU init
    if(imu.beginSPI(IMU_CS)) {
        Serial.println("Calibrating IMU...");
        delay(calibDelayIMU);
        imu.calibrateGyro(1, true);
        Serial.print("Done");
    } else Serial.println("IMU init failed!");

    //TFT init
    tft.init(240, 240);
    tft.setRotation(0);
    tft.fillScreen(0x00000);
    tft.print("Look at us. We just keep saying goodbye, don't we? But this isn't an end. It's a chance to make amends, to rectify mistakes. And it starts here: I was wrong.");
    delay(1000);

}

void loop() {
    now = millis();
    
    if(now - lastLDR >= delayLDR) {             //read LDR
        rawVolts = analogRead(LDR_ADC);
        voltsPercent = rawVolts * 100 / 1023;
        lastLDR = now;
    }
    
    if (now - lastIMU >= delayIMU) {            //read IMU
        imu.readAccel(ax, ay, az);
        imu.readGyro(gx, gy, gz);
        lastIMU = now;
    }
    
    btnAraw = digitalRead(BTN_A_PIN);           //read user input buttons
    btnBraw = digitalRead(BTN_B_PIN);
    btnCraw = digitalRead(BTN_C_PIN);
    
    if(readBtnA(now, btnAraw, btnDebounce, btnLongPress)) {
        feedPet(pixelPet);
    }                       
    if(readBtnB(now, btnBraw, btnDebounce, btnLongPress)) {
        playWithPet(pixelPet);
    }
    if(readBtnC(now, btnCraw, btnDebounce, btnLongPress)) {

    }
    checkSleep(pixelPet, )
    decayPetState(pixelPet);

}

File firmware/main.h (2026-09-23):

#pragma once

#include <SPI.h>
#include <7Semi_BMI323.h>

//pin assignments
const int SPI_MOSI = 11;
const int SPI_MISO = 13;
const int SPI_SCK = 20;

const int IMU_CS = 10;

const int LDR_ADC = 4;

const int BUZZ_PWM_PIN = 31;

const int BTN_A_PIN = 14;
const int BTN_B_PIN = 2;
const int BTN_C_PIN = 1;

const int BTN_RESET_PIN = 3;
const int BTN_BOOT_PIN = 0;

BMI323_7Semi imu;

unsigned long now;

//imu measurements
unsigned long lastIMU = 0;
int delayIMU = 300;
int calibDelayIMU = 2000;
float ax, ay, az;
float gx, gy, gz;

//LDR measurements
unsigned long lastLDR = 0;
int delayLDR = 500;
int rawVolts;
int voltsPercent;

//button values
bool btnBoot;

bool btnAraw;
bool btnBraw;
bool btnCraw;
bool btnA;
bool btnB;
bool btnC;
int btnDebounce = 50;
int btnLongPress = 100;

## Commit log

2026-09-22 Add enclosure body files
    [EnclosureBottomV2.3mf, EnclosureTopV2.3mf]
2026-09-24 Rename 2171790001.kicad_sym to 2026-06-04_18-40-30.kicad_sym.kicad_sym
2026-09-24 Rename 2026-06-04_18-40-30.kicad_sym.kicad_sym to 2026-06-04_18-40-30.kicad_sym
